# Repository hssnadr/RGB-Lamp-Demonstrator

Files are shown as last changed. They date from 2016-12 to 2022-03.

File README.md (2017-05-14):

# RGB Lamp

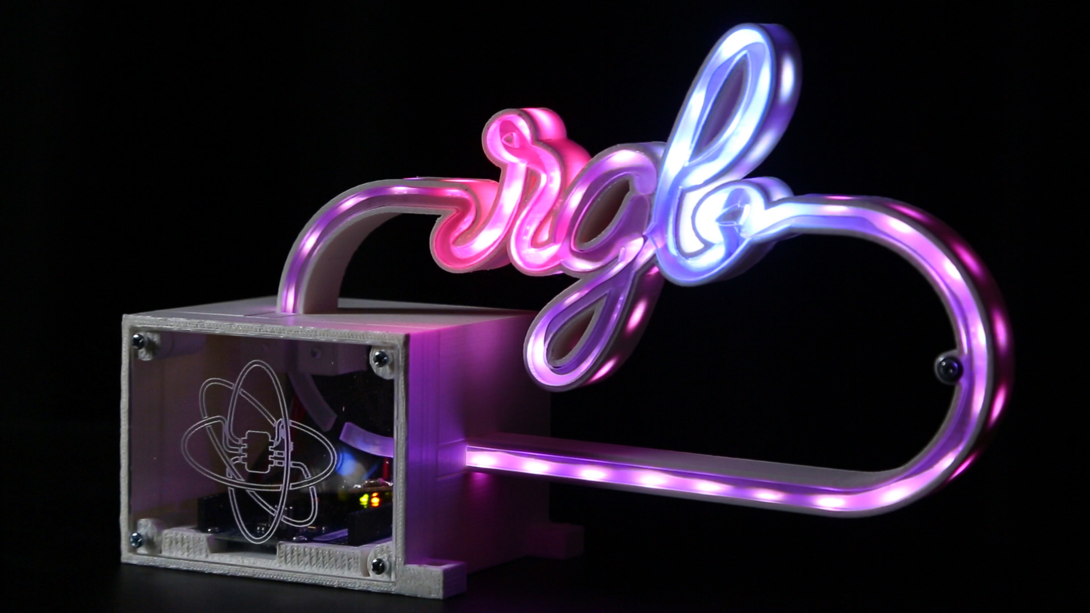
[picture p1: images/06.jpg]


## Presentation

This lamp project is a demonstrator dedicated to highlight Mobile-Lab technological resources. It allows to interact with its colors by moving the hand. How does it work ?
 1. the user records 3 gestures, each one corresponding to a color component of the light (red, green or blue);
 2. then he moves his hand reproducing those gestures, this way he can regulate the proportion of RGB colors in the light and create any kind of colors;
 3. the user can record any kind of gesture, let's try different patterns!

Full presentation video on Vimeo: https://vimeo.com/197767041

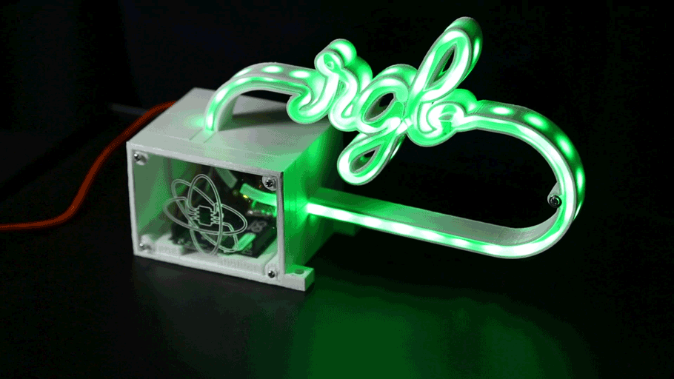
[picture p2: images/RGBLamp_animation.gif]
  
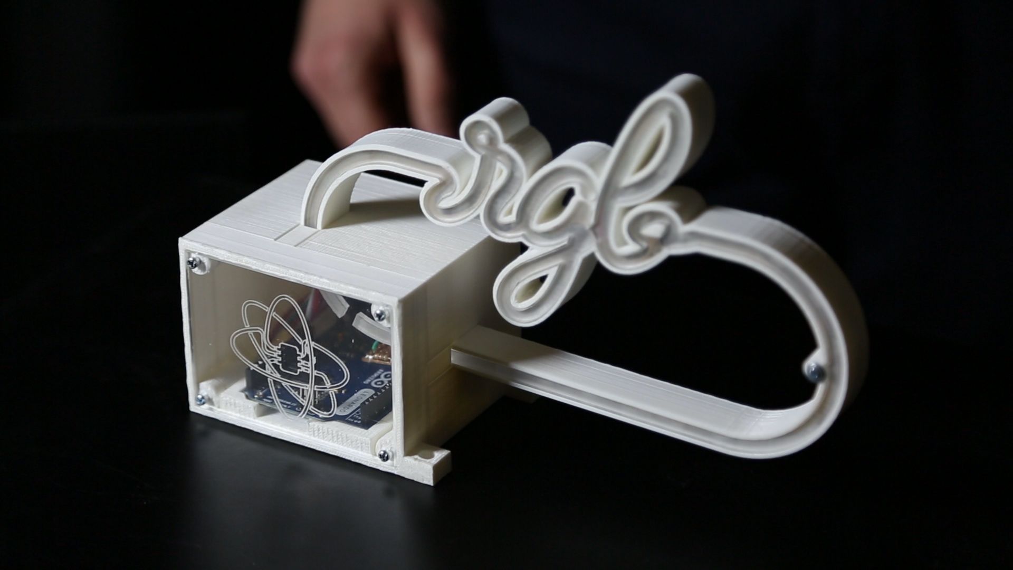
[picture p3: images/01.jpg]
  
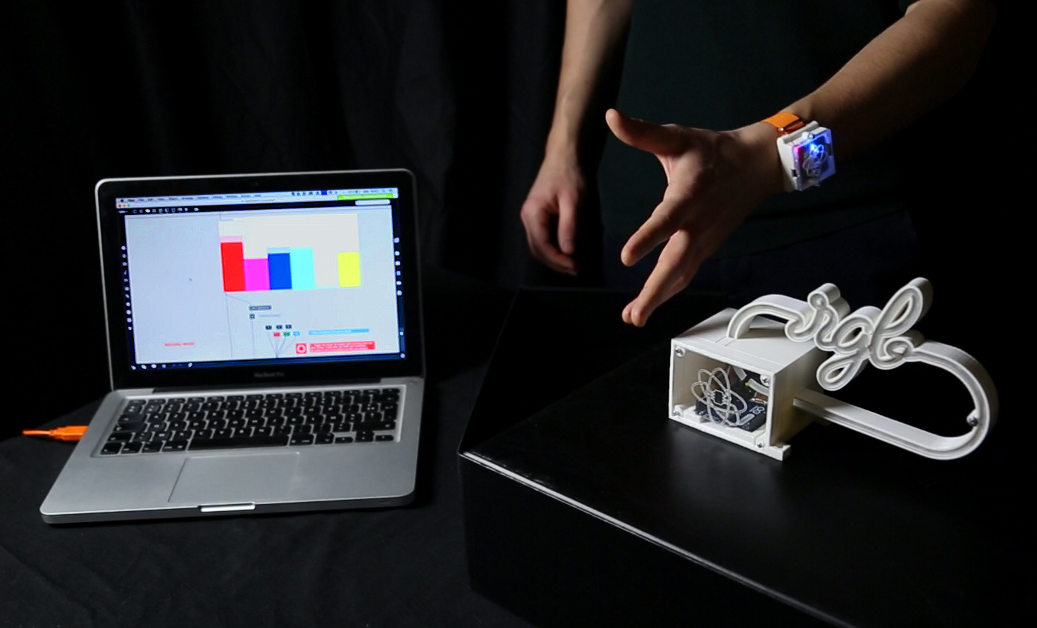
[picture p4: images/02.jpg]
  
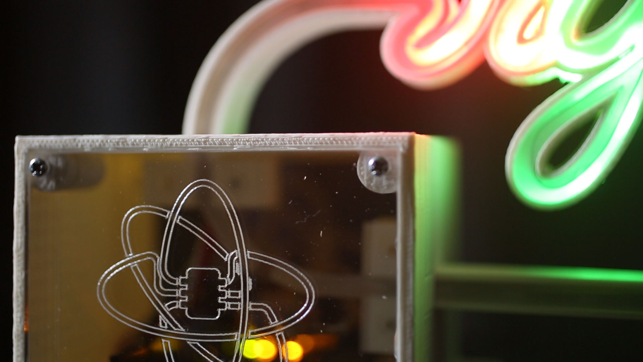
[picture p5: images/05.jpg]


The purpose of this project is to highlight usages around those technologies and enhance collaboration with potential development partners.

This demonstrator was developed using **Movuino** gesture sensor and **IRCAM** algorithm libraries for real time gesture recognition. This library is include into their MuBu package for Max/MSP. It gives Max objects to easily store and manage data flows and includes their XMM libraries.
* Presentation: https://www.julesfrancoise.com/mubu-probabilistic-models/
* Download link: http://forumnet.ircam.fr/fr/produit/mubu/

## Content
Here you will find:
* **1_Movuino_FirmwareOSC/Arduino** this folder contains the firmware for the Movuino. You can edit and use it with the Arduino software;
* **2_CybRGB_ArduinoFirmware** this folder contains the firmware of the lamp. You can also edit it using the Arduino software;
* **CybRGB.maxpat** this file is used as interface to control the lamp.

## Installation
  
### Movuino (1_Movuino_FirmwareOSC/)
* Download and install the Arduino software: https://www.arduino.cc/en/Main/Software
* Download and install the CP2014 driver: http://www.silabs.com/products/mcu/Pages/USBtoUARTBridgeVCPDrivers.aspx
* Inside Arduino
  * Install the card ESP8266 following those instructions: https://learn.sparkfun.com/tutorials/esp8266-thing-hookup-guide/installing-the-esp8266-arduino-addon
 * Go to Tools/Board, select "Adafruit HUZZAH ESP8266" with:
      * CPU Frequency: 80 MHz
      * Flash Size: 4M (3M SPIFFS)
      * Upload Speed: 115200
      * Port: the one corresponding to the Movuino
  * Copy the content of the Arduino folder into your own Arduino folder (Macintosh and Windows: Documents/Arduino). It includes the libraries you need, but you can also install them by yourself. In the Arduino software go to "Sketch/Include Library/Manage Libraries...", here seek and install:  
    * I2Cdev
    * OSC
    * MPU6050
      * for this one you need to make a correction in the library file. Go to Arduino/libraries/MPU6050/ and edit the file "MPU6050.h" (open it in NotePad, SublimeText, NotePad++ or anykind of text editor).
        * line 58, replace the line: `#define MPU6050_DEFAULT_ADDRESS MPU6050_ADDRESS_AD0_LOW`
        * **by:** `#define MPU6050_DEFAULT_ADDRESS MPU6050_ADDRESS_AD0_HIGH`
  * Restart Arduino and follow instructions inside the code (ip, rooter, password, port...)
     * `const char * ssid = "my_box_name";` set the name of your wifi network
     * `const char * pass = "my_password";` type the password of the network
     * `const char * hostIP = "192.168.1.35";` set the ip address of **YOUR COMPUTER** which is also connected to the same Wifi network and on which you will use the Max file
     * `const unsigned int port = 7400;` (optional) here you can set the port on which the data are sent. If you don't use other ports or if you have no idea of what I'm talking about you can let 7400.
     * `const unsigned int localPort = 3011;` (optional) here you can set the port on which Movuino can receive OSC message. Idem, better to let it at 3011.
  * Upload firmware and check on the Arduino monitor window if everything is good!
  * You can shut down (partially) and turn on the Movuino by pressing the button during 1 second.
  * **You can also send message to the Movuino, also using OSC.**
  
### RGB Lamp firmware (2_CybRGB_ArduinoFirmware/)
The lamp has been developped with an Arduino Leonardo and NeoPixel Led Strip from Adafruit. Here you will find some information concerning the Led Strip:
* How to use it: https://learn.adafruit.com/adafruit-neopixel-uberguide/basic-connections
* Concerning the batteries: https://learn.adafruit.com/adafruit-neopixel-uberguide/basic-connections

To use it you only need to plug the USB port to your computer, to plug the power supply and to directly go next step with the Max/MSP patch.
  
To modify the firmware, download the content of the folder and paste it into your Arduino folder (Macintosh and Windows: Documents/Arduino). The folder include the NeoPixel library but I recommend you to download it yourself: in the Arduino software go to "Sketch/Include Library/Manage Libraries...", here seek and install "Adafruit NeoPixel".
  
Now you can play with the code and update the firmware. Be sure to choose "Arduino Leonardo" (Tools/Board/) before to upload the code.
  
### CybRGB.maxpat
To run the Max file, you'll need to install the MuBu package. It's very simple!
* download the package on the MuBu page: http://forumnet.ircam.fr/fr/produit/mubu/
* unzip the folder "MuBuForMax" and simply past it into the proper folder:
 * **On Macintosh**
    * go to Applications folder, right click on the **Max** icon and choose "Show Package Contents"
    * paste the MuBuForMax folder into Contents/Resources/C74/packages
    * launch or restart Max and that's it.
  * **On Windows**
    * paste the MuBuForMax folder into /Documents/Max 7/Packages
    * launch or restart Max and that's it.
    
Before to use the script you will also need to make the lamp recognized by the Max patch. Once again it's very simple, you simply need plug the lamp to your computer, then print the available USB port of your computer, check which one correspond  to the lamp and finally set this port into the Max patch. Here the principle (not the same patch but exactly the same workflow):



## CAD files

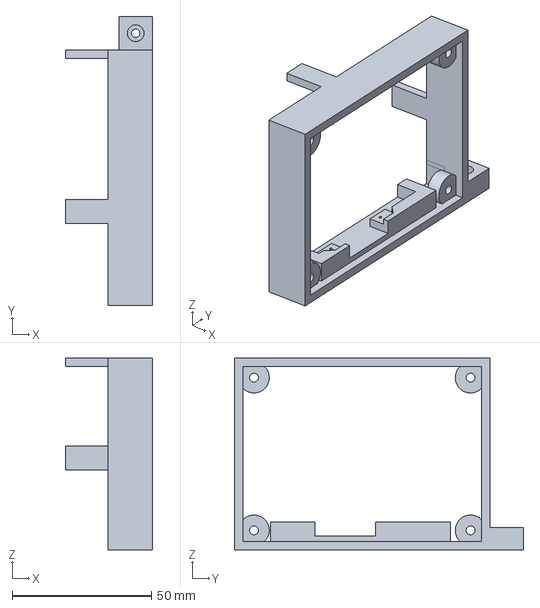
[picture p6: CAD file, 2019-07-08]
01_MakingRessources/3DModels/STP/Base_Front.stp
31.1 x 103.8 x 68.9 mm

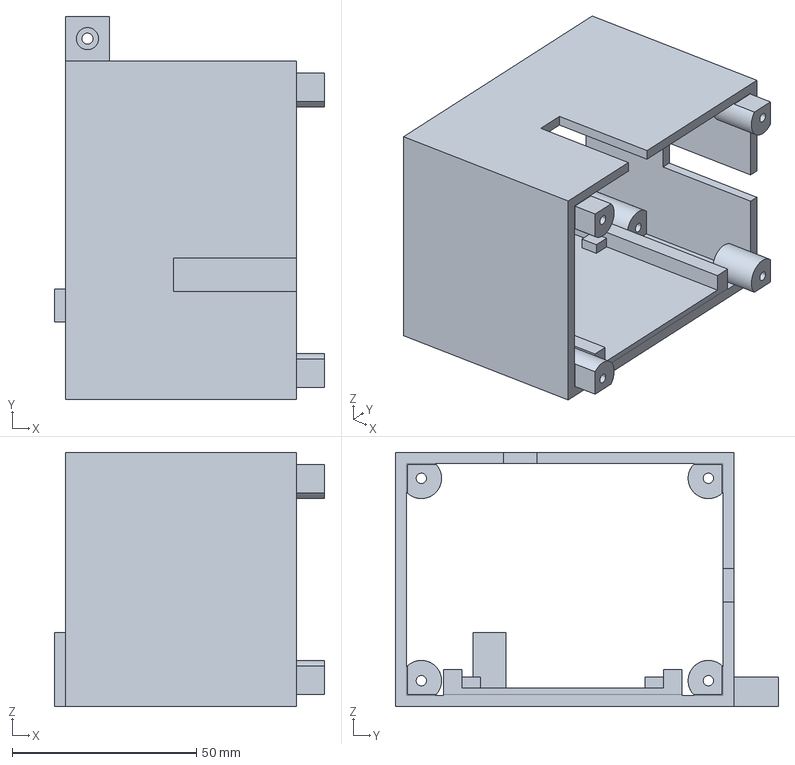
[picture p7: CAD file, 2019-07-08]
01_MakingRessources/3DModels/STP/Base_Back.stp
73.3 x 103.8 x 68.9 mm

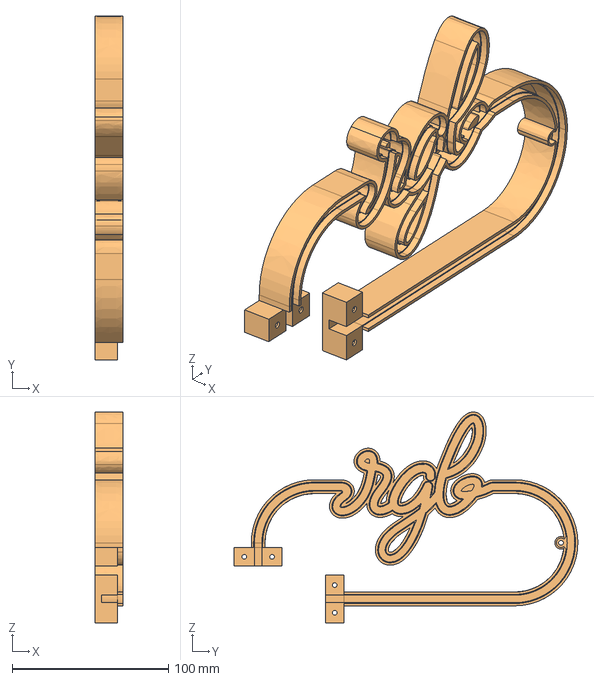
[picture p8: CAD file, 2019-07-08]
01_MakingRessources/3DModels/STP/RGB_Case.stp
17.7 x 220.0 x 135.0 mm

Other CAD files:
01_MakingRessources/3DModels/CATIA/Base_Back.CATPart
01_MakingRessources/3DModels/CATIA/Base_Front.CATPart
01_MakingRessources/3DModels/CATIA/RGBLamp_Product.CATProduct
01_MakingRessources/3DModels/CATIA/RGB_Case.CATPart
01_MakingRessources/3DModels/STL/Base_Back.stl
01_MakingRessources/3DModels/STL/Base_Front.stl
01_MakingRessources/3DModels/STL/RGB_Case.stl

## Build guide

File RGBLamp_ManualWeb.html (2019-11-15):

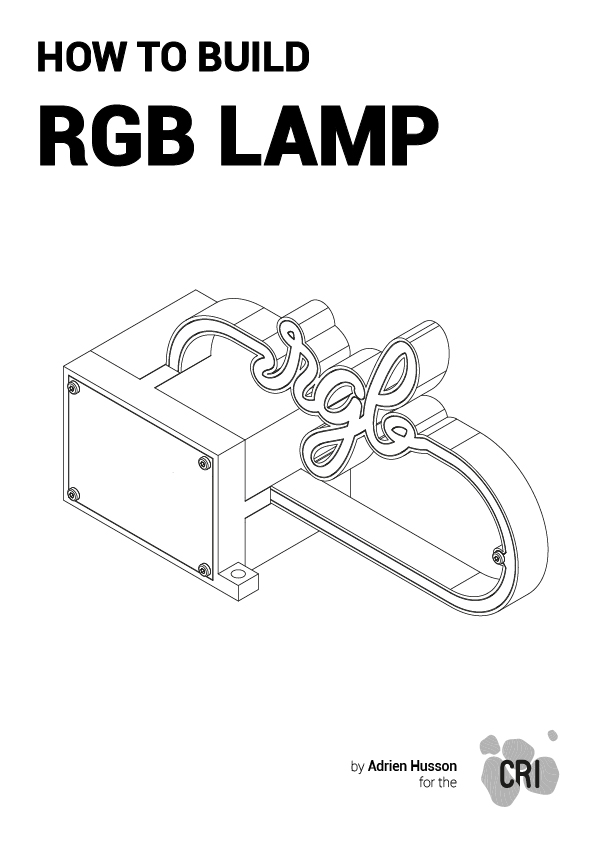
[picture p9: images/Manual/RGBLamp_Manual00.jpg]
RGBLamp_Manual00


Download manual (https://github.com/hssnadr/RGB-Lamp-Demonstrator/raw/master/RGBLamp_ManualBooklet.pdf)

### Furnitures

RGBLampGif

Get all the files you'll need and start following the tutorial

Download ressources (https://github.com/hssnadr/RGB-Lamp-Demonstrator/archive/master.zip) See on Github (https://github.com/hssnadr/RGB-Lamp-Demonstrator)

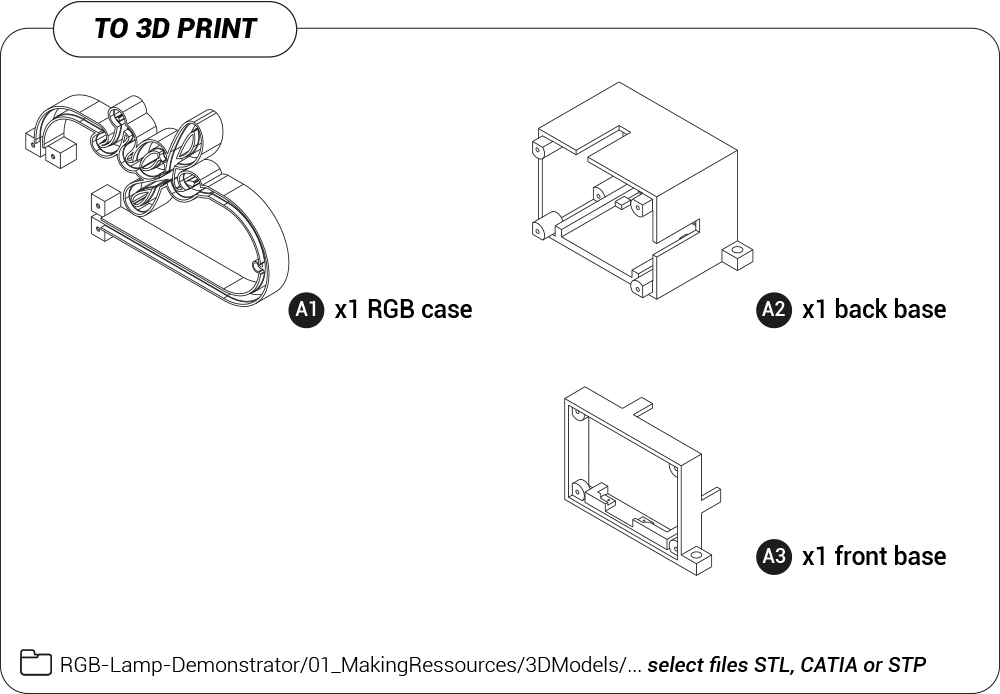
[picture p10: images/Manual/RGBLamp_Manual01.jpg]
RGBLamp_Manual01
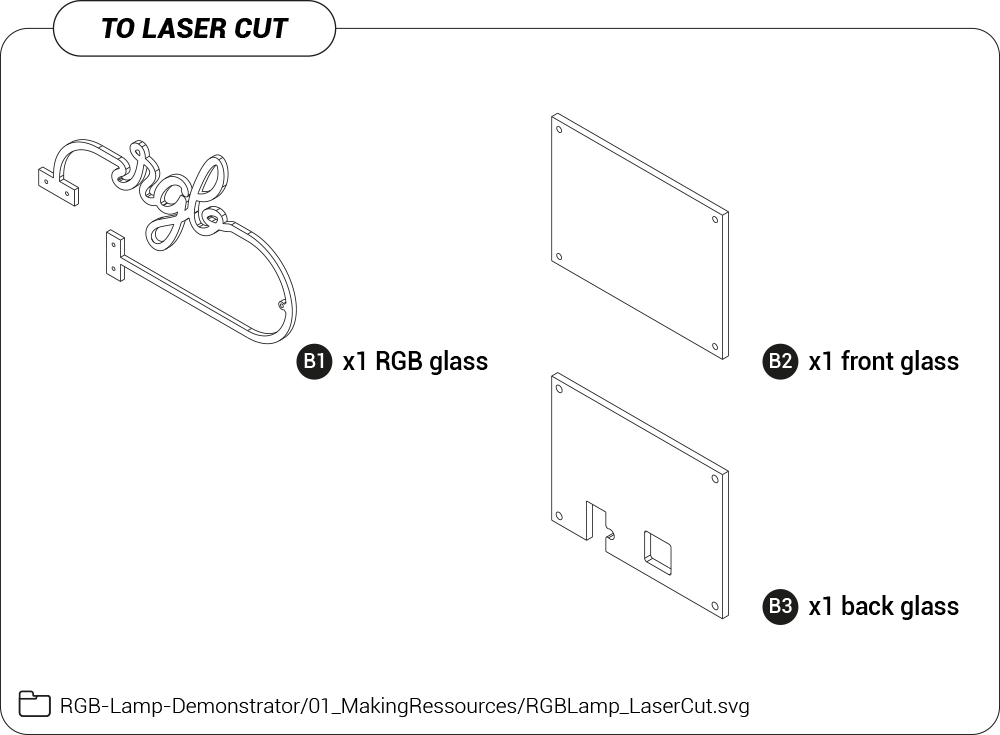
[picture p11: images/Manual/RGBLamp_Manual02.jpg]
RGBLamp_Manual02
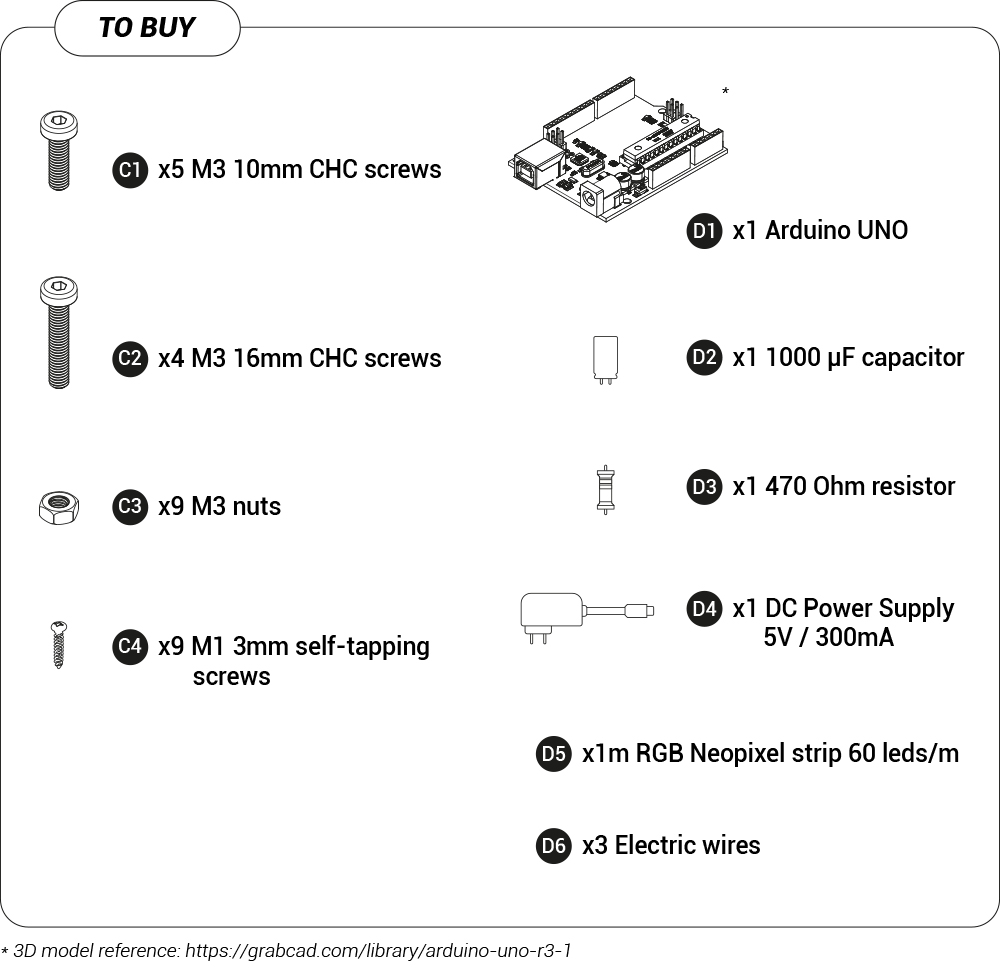
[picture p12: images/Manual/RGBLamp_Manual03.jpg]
RGBLamp_Manual03
  

### Electronic

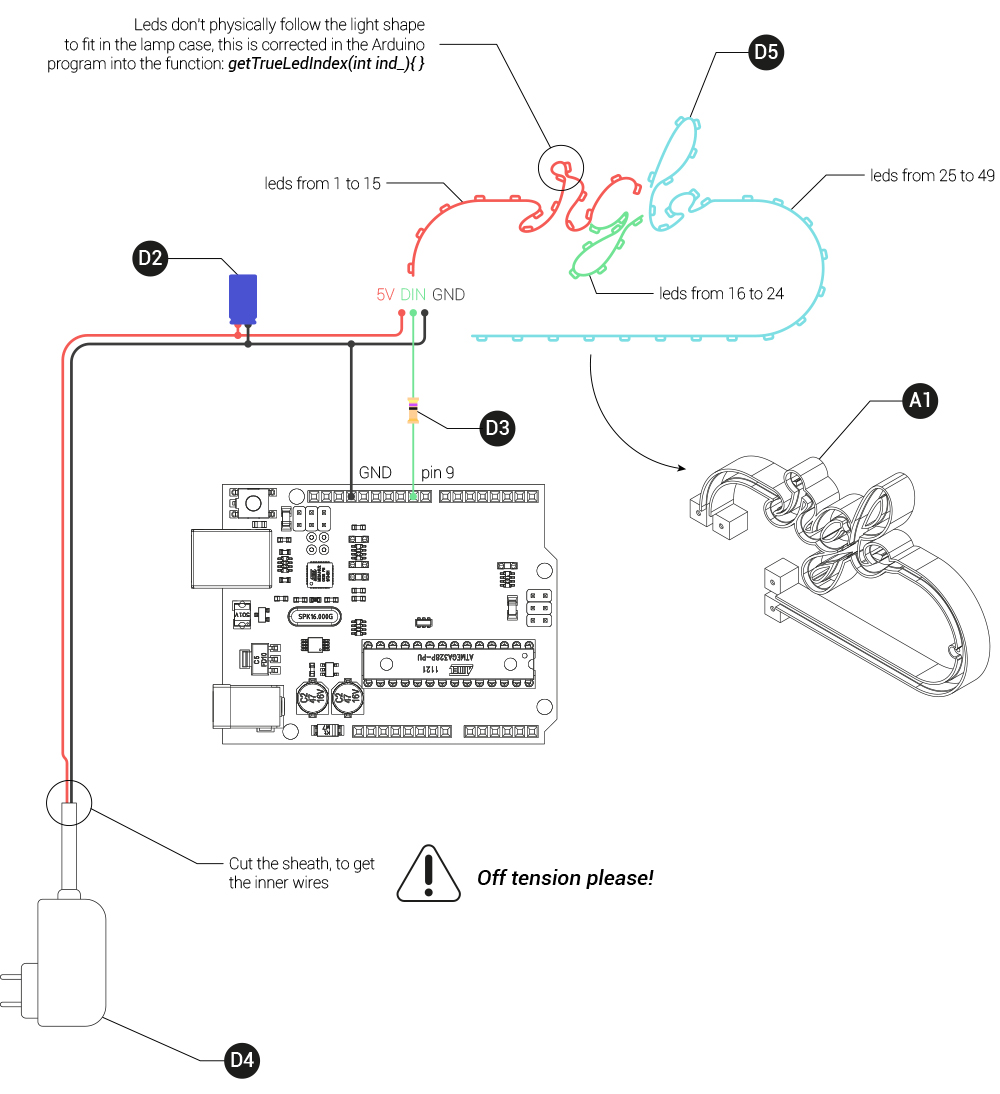
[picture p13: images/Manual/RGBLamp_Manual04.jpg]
RGBLamp_Manual04
RGBcloseUp 

### Assembly

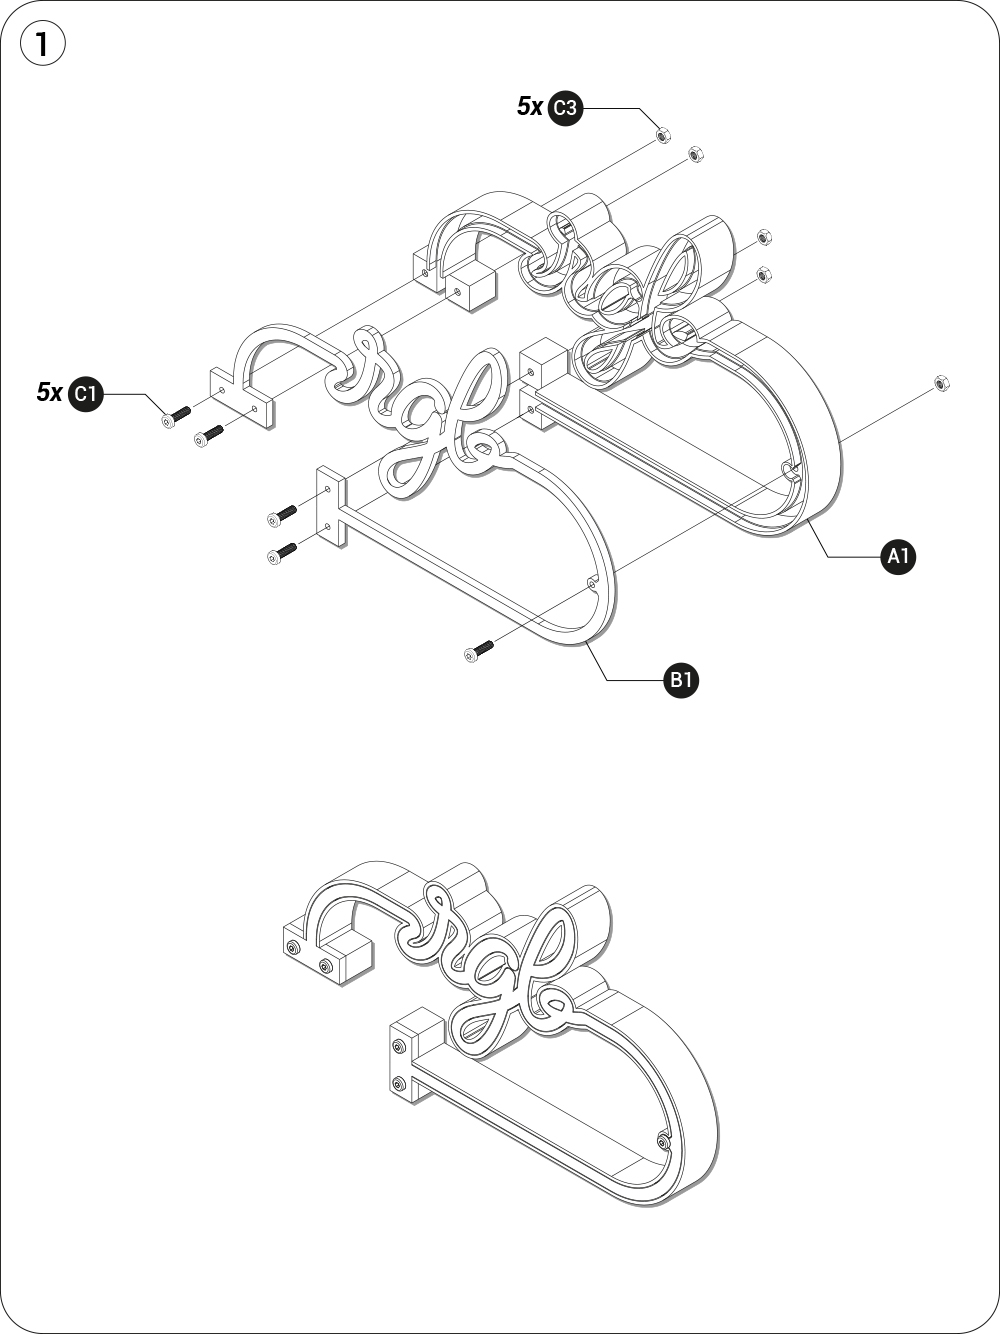
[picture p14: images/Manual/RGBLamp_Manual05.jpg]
RGBLamp_Manual05
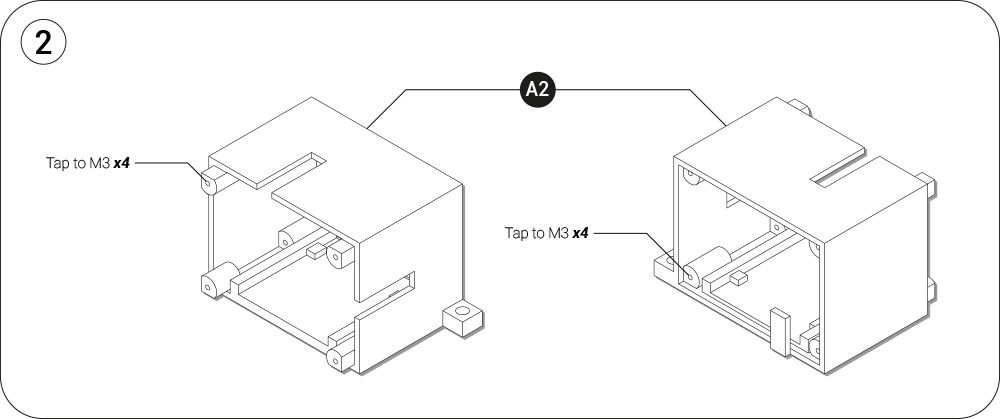
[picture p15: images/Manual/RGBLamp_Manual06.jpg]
RGBLamp_Manual06
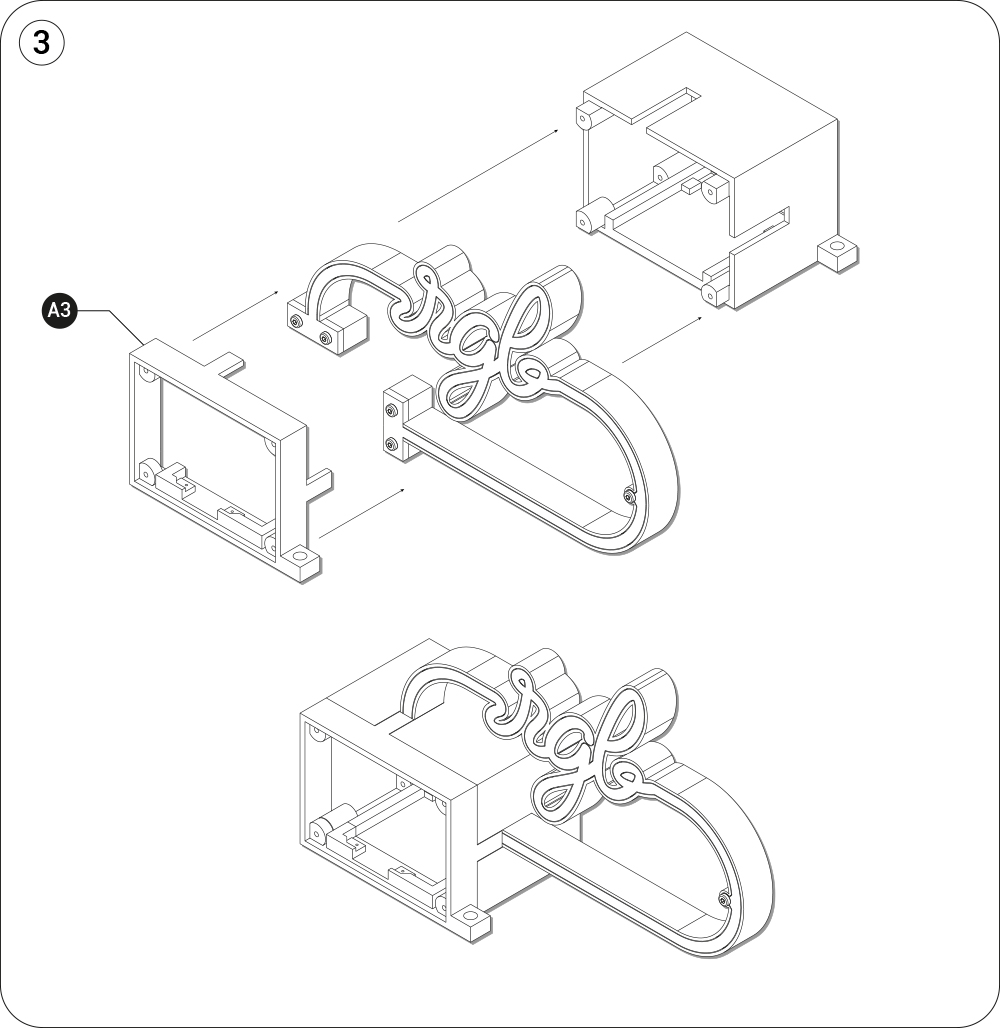
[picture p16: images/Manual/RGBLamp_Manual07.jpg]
RGBLamp_Manual07
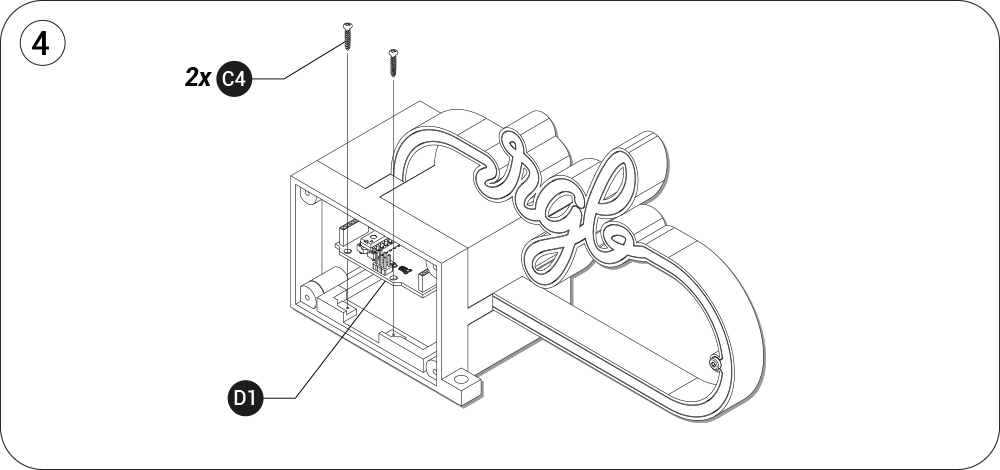
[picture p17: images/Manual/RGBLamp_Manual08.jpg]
RGBLamp_Manual08
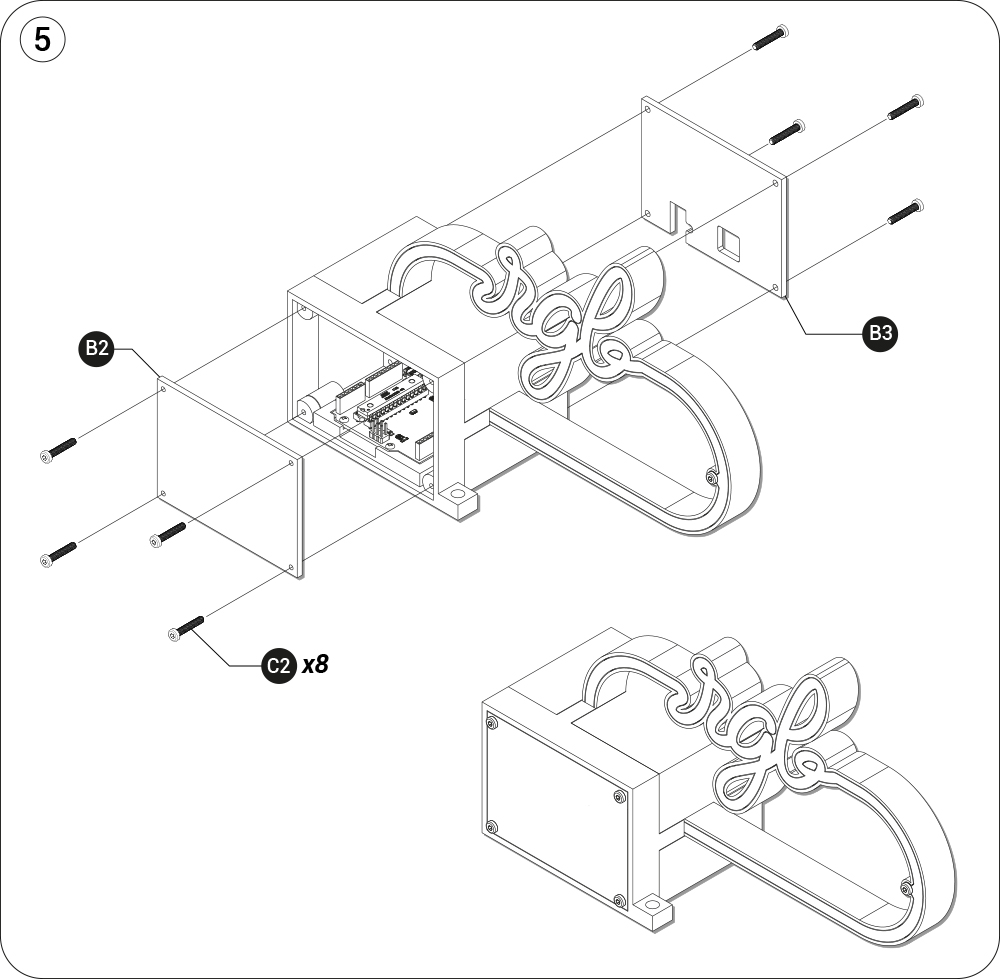
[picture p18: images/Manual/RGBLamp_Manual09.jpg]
RGBLamp_Manual09
RGB3Dprint     

### Set-Up

RGB02

PictoArduino

Download and install Arduino (https://www.arduino.cc/en/main/software)

1. Run the RGBLamp.ino firmware with Arduino
2. You’ll need to install the Adafruit Neopixel library:
  Sketch/Include a library/Manage libraries
3. Search for «Adafruit Neopixel» in the search tab and the install latest version
4. Upload the program on your board

PictoFolder

RGB-Lamp-Demonstrator/02_ArduinoFirmware/RGBLamp/ (https://github.com/hssnadr/RGB-Lamp-Demonstrator/tree/master/02_ArduinoFirmware/RGBLamp)

PictoProcessing

Download and install Processing (https://processing.org/download/)

  1. Run the RGBLamp.pde file with Processing while the lamp is plugged on a USB port of your computer
  2. You’ll need to install the oscP5 library:
    Sketch/Import library.../Add a library...
  3. Search for «oscP5» in the search tab and the install latest version
  4. Go to line 40 into the Processing code and set the USB port where your Arduino is plugged

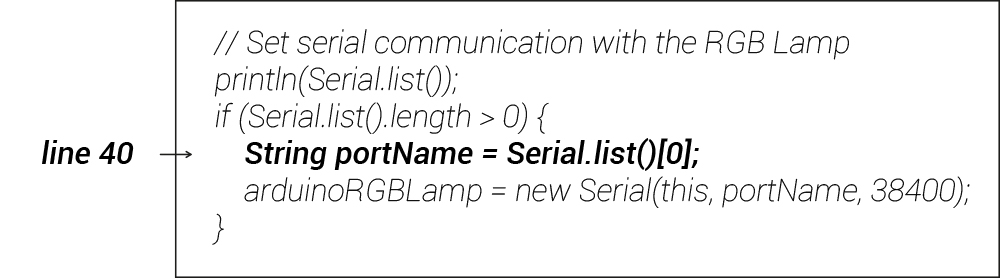
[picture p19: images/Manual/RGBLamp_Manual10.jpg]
RGBLamp_Manual10


PictoFolder

RGB-Lamp-Demonstrator/03_ProcessingApplication/RGBLamp/ (https://github.com/hssnadr/RGB-Lamp-Demonstrator/tree/master/03_ProcessingApplication/RGBLamp)

PictoProcessing

Download and install Movuina (http://www.movuino.com#dlmovuina)

Launch Movuina and set-up by following the Quick Start tutorial

Quick start tutorial (http://www.movuino.com/index.php/quick-start/)

Once its done, you can play with the XMM algorithm (http://ismm.ircam.fr/software/xmm-probabilistic-models-for-motion-recognition-and-mapping/) developped by IRCAM

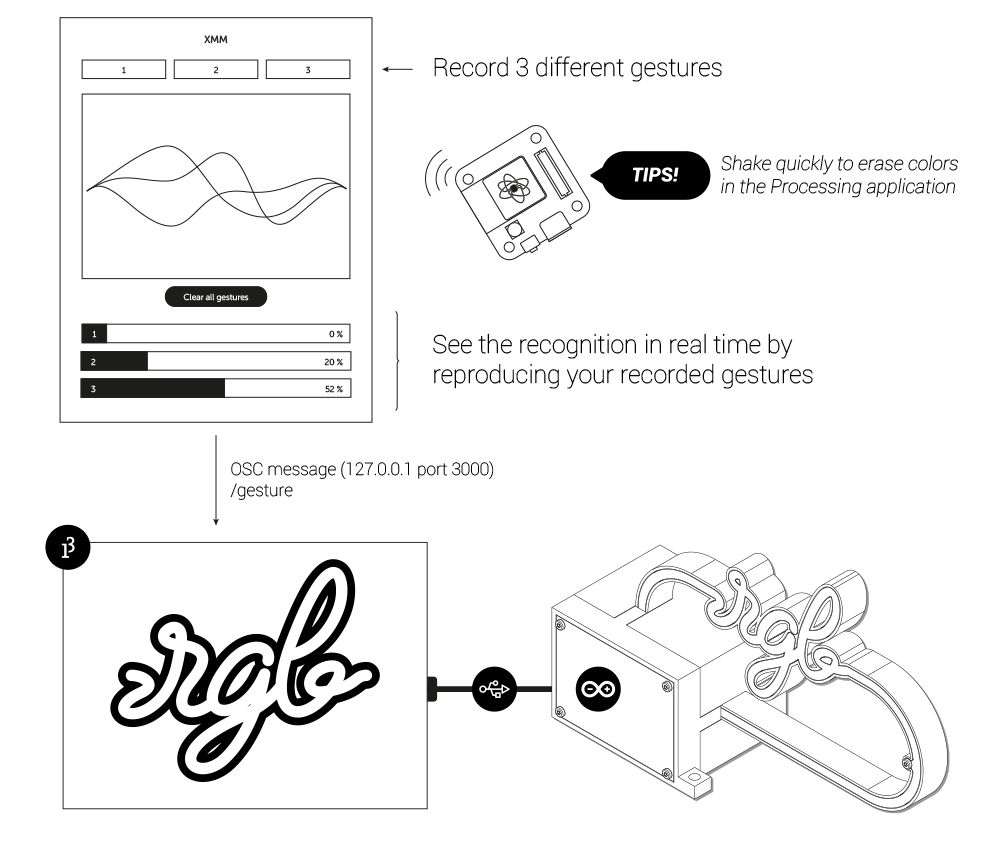
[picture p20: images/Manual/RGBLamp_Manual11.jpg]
RGBLamp_Manual11


The data are automatically sent to Processing and you can enjoy the reaction!

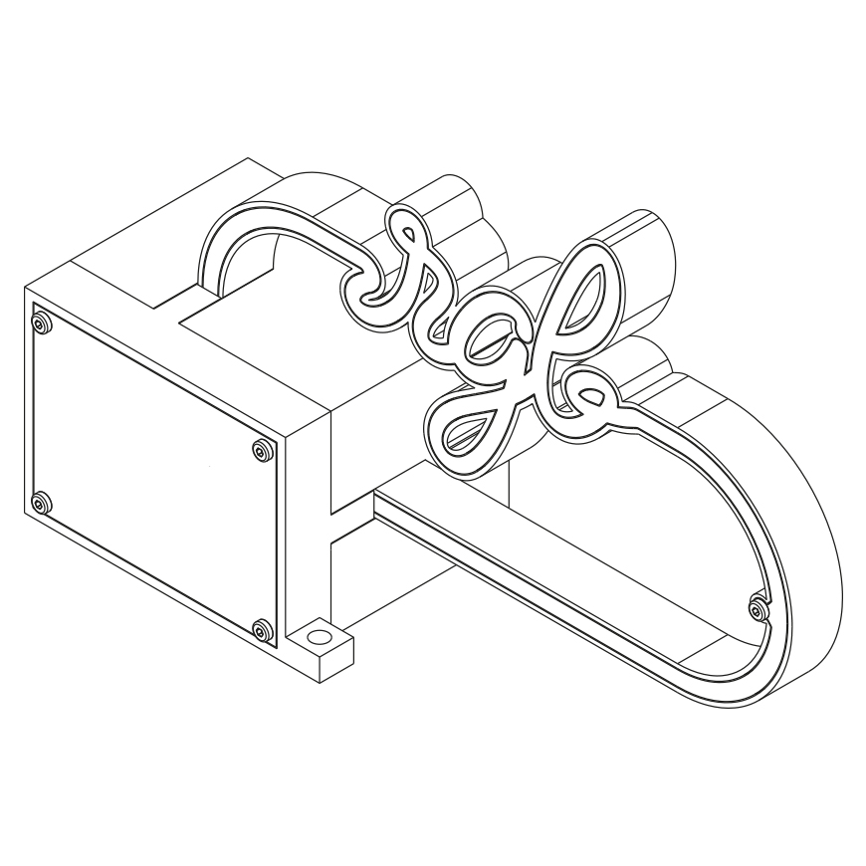
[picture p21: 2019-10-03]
images/Manual/RGBLamp_Square.jpg

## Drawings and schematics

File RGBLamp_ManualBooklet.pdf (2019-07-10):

# RGB LAMP

# HOW TO BUILD

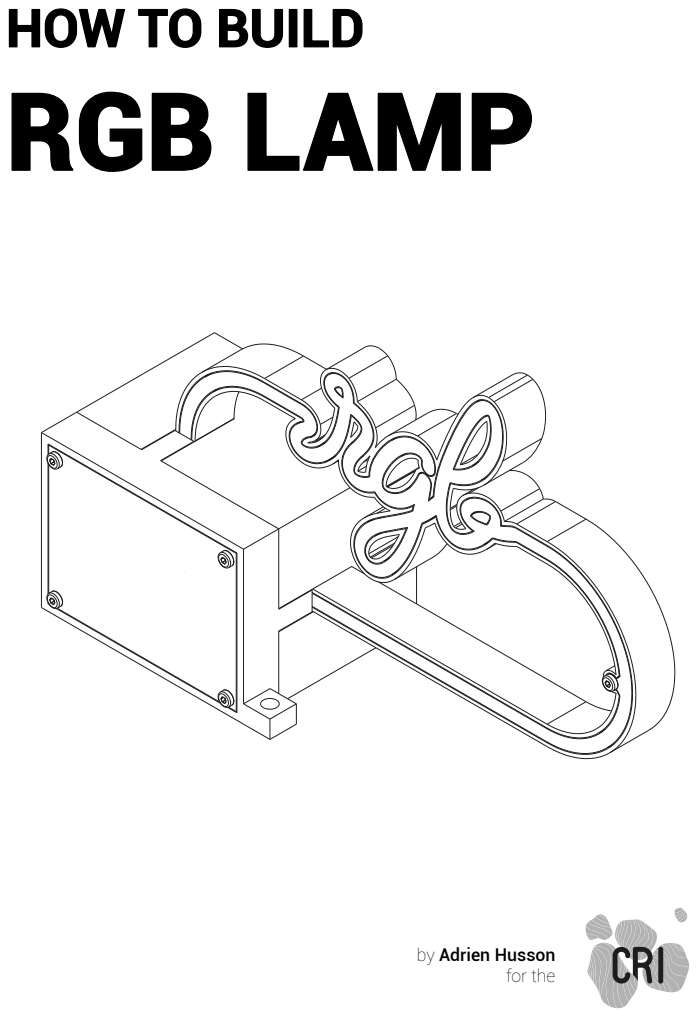
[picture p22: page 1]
for the

by Adrien Husson

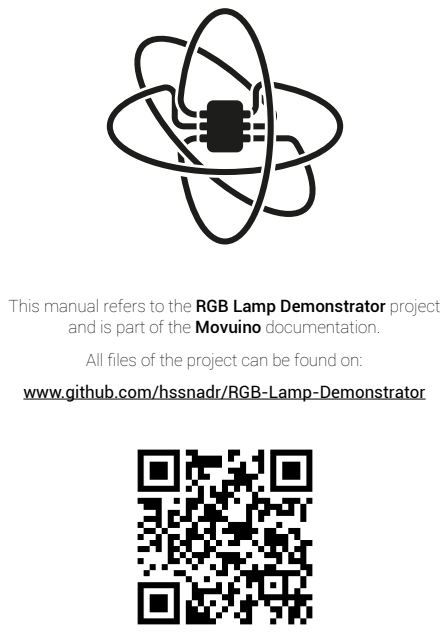
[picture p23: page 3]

This manual refers to the RGB Lamp Demonstrator project
and is part of the Movuino documentation.
All files of the project can be found on:
www.github.com/hssnadr/RGB-Lamp-Demonstrator

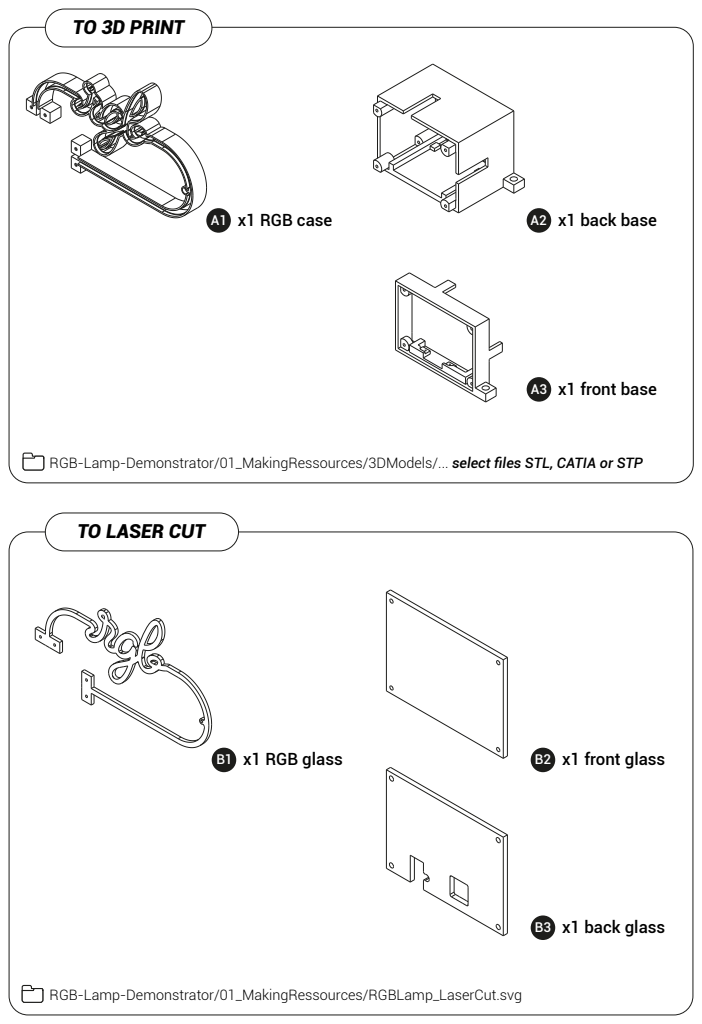
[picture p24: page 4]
TO 3D PRINT; x1 back base; x1 front base; A1 x1 RGB case; B1 x1 RGB glass; B2 x1 front glass; B3 x1 back glass

RGB-Lamp-Demonstrator/01_MakingRessources/3DModels/... select files STL, CATIA or STP

TO LASER CUT

RGB-Lamp-Demonstrator/01_MakingRessources/RGBLamp_LaserCut.svg

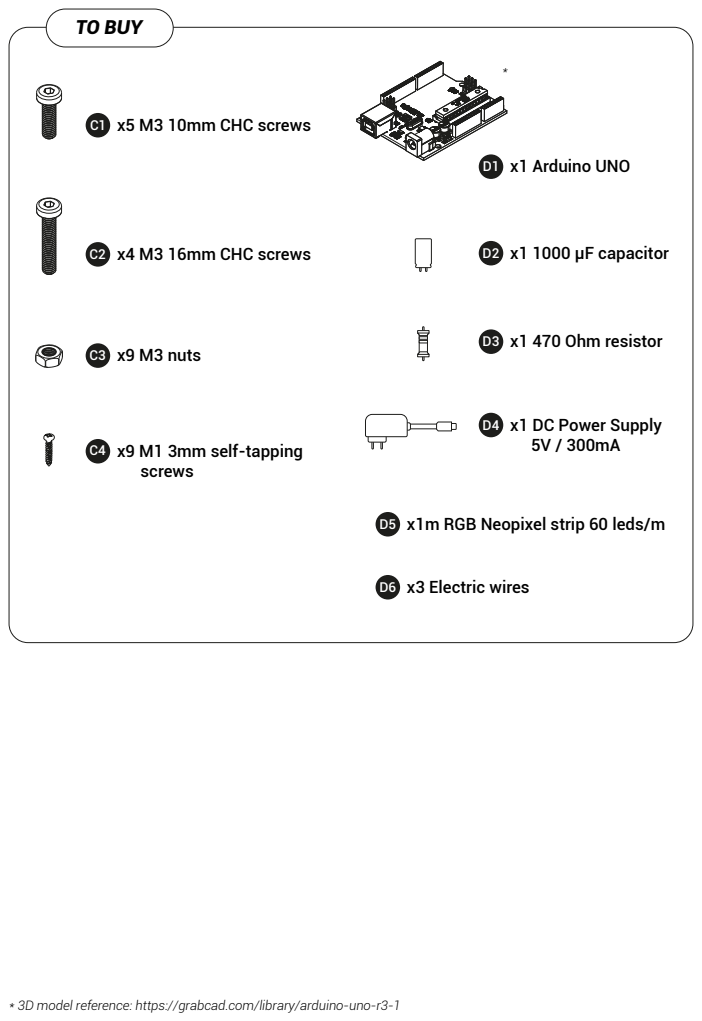
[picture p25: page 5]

D5 x1m RGB Neopixel strip 60 leds/m

* 3D model reference: https://grabcad.com/library/arduino-uno-r3-1

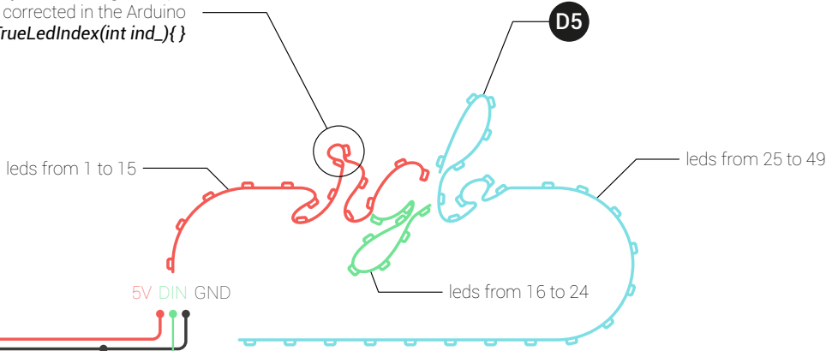
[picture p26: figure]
leds from 25 to 49 leds from 1 to 15; 5V DIN GND; leds from 16 to 24
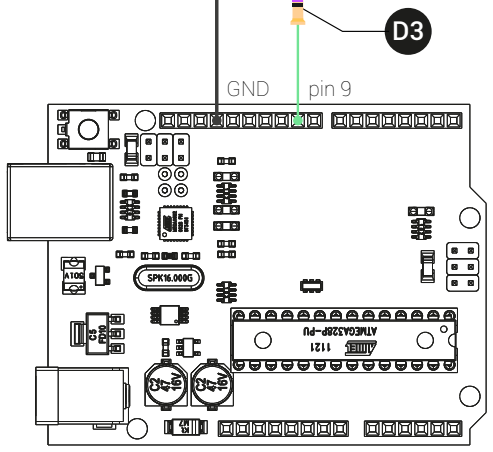
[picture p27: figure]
GND; pin 9

Cut the sheath, to get
the inner wires

Leds don’t physically follow the light shape to fit in the lamp case, this is corrected in the Arduino program into the function: getTrueLedIndex(int ind_){ }

# ELECTRONIC

To make the electronic part, you need to cut your 1 meter Neopixel leds strip into 3 parts, then sold it in a way it fits into the RGB case and following this diagram.

Off tension please!

D2

D4

A1

# ASSEMBLY

1

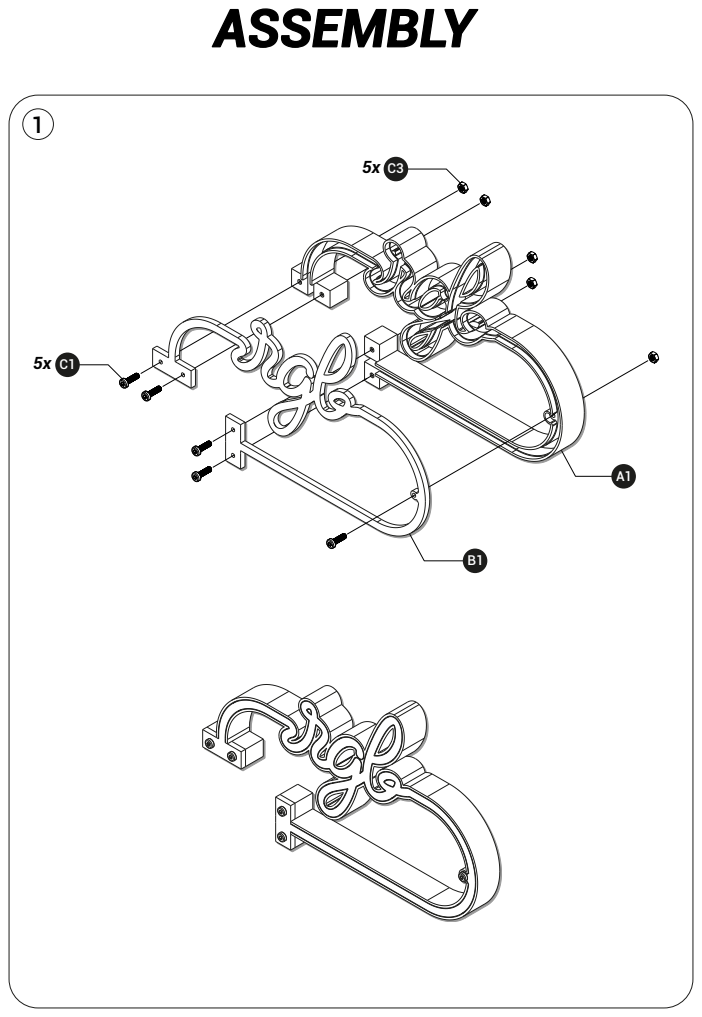
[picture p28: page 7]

2

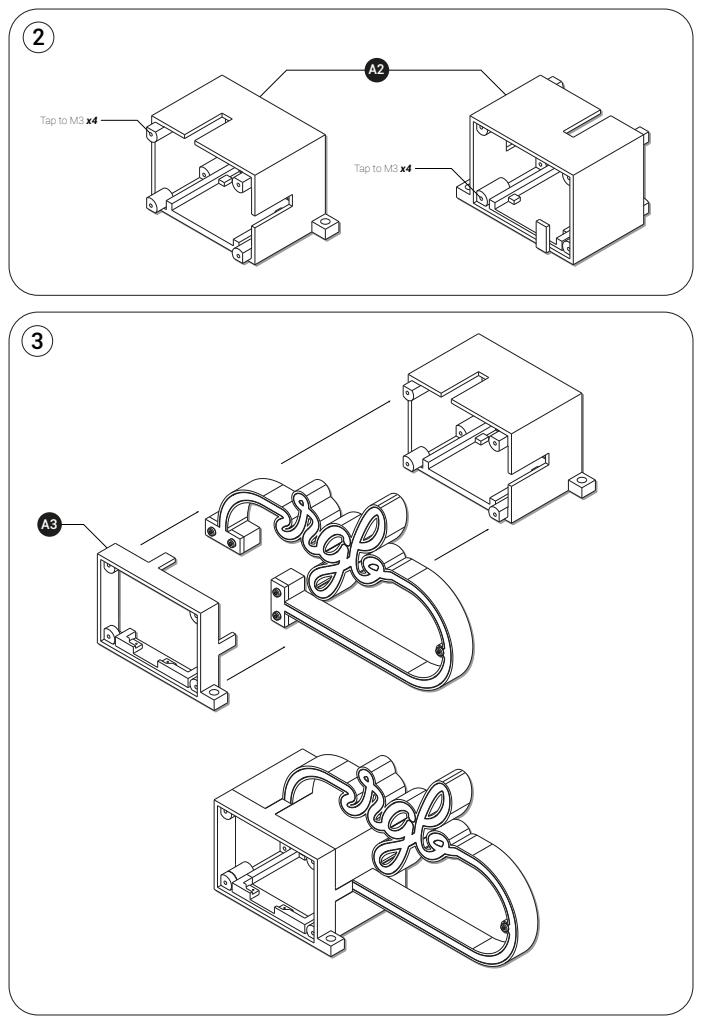
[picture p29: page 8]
Tap to M3 x4

4

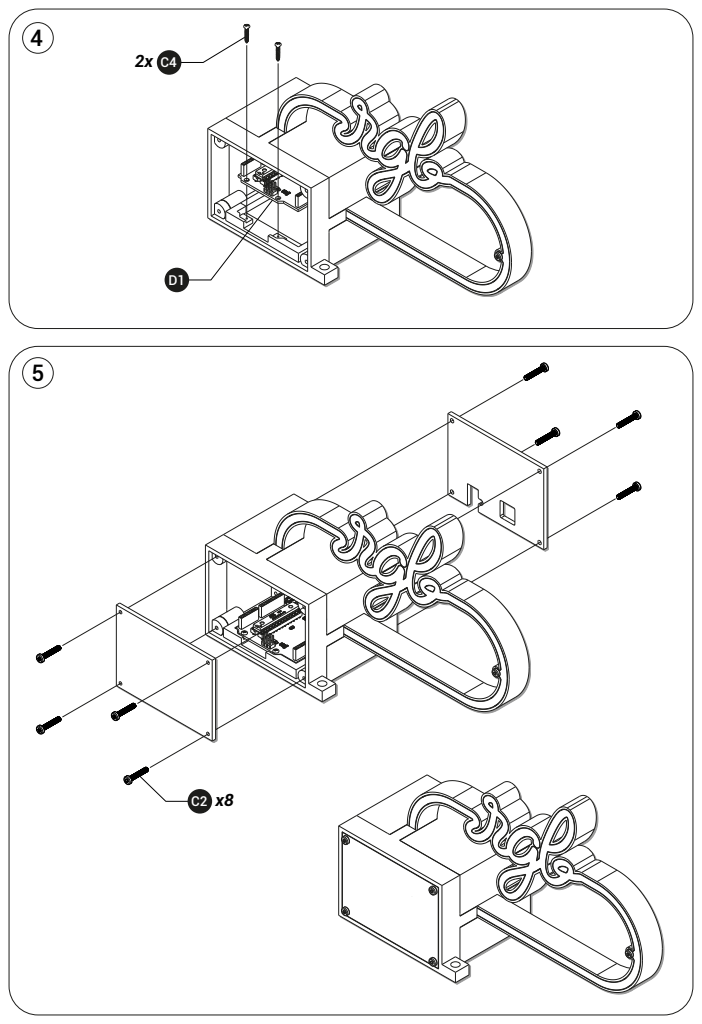
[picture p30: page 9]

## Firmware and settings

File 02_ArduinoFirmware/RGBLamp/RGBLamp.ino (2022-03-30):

/*
 * This project is part of the Movuino demo tutorial from: http://www.movuino.com/
 * Page of the project: http://www.movuino.com/index.php/portfolio/rgb-lamp/
 * Github: https://github.com/hssnadr/RGB-Lamp-Demonstrator
 */

// LED strip
#include <Adafruit_NeoPixel.h>
#ifdef __AVR__
#include <avr/power.h>
#endif
#define pinLed 9                                                                 // Pin controling the led strip behavior
#define nPix 49                                                                  // number of pixels used in the strip
Adafruit_NeoPixel strip = Adafruit_NeoPixel(nPix, pinLed, NEO_GRB + NEO_KHZ800); //   NEO_KHZ800  800 KHz bitstream (most NeoPixel products w/WS2812 LEDs)

// Auto loop: play random animation before first serial input
bool _isAutoLoop = true;

// RGB values
int stripOrder[] = {0, 1, 2, 3, 4, 5, 6, 7, 9, 8, 10, 11, 12, 14, 13, 15, 16, 17, 21, 20, 19, 18, 22, 28, 27, 26, 25, 24, 23, 29, 30, 32, 31, 33, 34, 35, 36, 37, 38, 39, 40, 41, 42, 43, 44, 45, 46, 47, 48};
boolean isNewColor = false;
byte stripRed[nPix];
byte stripGreen[nPix];
byte stripBlue[nPix];
boolean isColorSet;
int r = 0;
#define r0 4  // led index where letter 'R' starts
#define r1 13 // led index where letter 'R' ends
int g = 0;
#define g0 13 // led index where letter 'G' starts
#define g1 23 // led index where letter 'G' ends
int b = 0;
#define b0 23 // led index where letter 'B' starts
#define b1 34 // led index where letter 'B' ends

long timer0;
long timer1;

// Serial variables
int inByte = 0;    // incoming serial byte
char buffer[40];   // buffer to store incoming bytes
int index = 0;     // current index of the buffer
char msgAdr = 'X'; // address of received messages
int msgVal = -1;   // values of received messages

void setup()
{
  // Serial Port begin
  Serial.begin(9600);

  // LED strip setup
  // strip.setBrightness(50);
  strip.begin(); // This initializes the NeoPixel library.
  strip.show();  // Initialize all pixels to 'off'
  timer0 = millis();
}

void loop()
{
  if (_isAutoLoop)
  {
    autoLoop();
  }
  // Serial.println("HERE");
  HHMM_follower();
  // WheelAnimation();
}

int getTrueLedIndex(int ind_)
{
  // REAL STRIP ORDER
  // to be integrated properly into the lamp, the led strip has been cut and re-solder.
  // I had to modify the order of the led to get the expected effect. This function permits to
  //{1,2,3,4,5,6,7,8,10,9,11,12,13,15,14,16,17,18,22,21,20,19,23,29,28,27,26,25,24,30,31,33,32,34,35,36,37,38,39,40,41,42,43,44,45,46,47,48,49}
  //       |                        |                             |                             |
  //      red                     green                          blue                          end
  //"RED" = 5 -> 13
  //"GREEN" = 15 -> 23
  //"BLUE" = 29 -> 34

  return stripOrder[ind_];
}

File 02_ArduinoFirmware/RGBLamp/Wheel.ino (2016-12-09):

int indWheel = 0;
int oldIndWheel1 = 0;
int oldIndWheel2 = 0;
boolean isLoading = false;

void WheelAnimation() {
  if (!isLoading) {
    shutDownStrip();
  }

  setPixWheel(indWheel, 1);
  setPixWheel(oldIndWheel1, 4);
  setPixWheel(oldIndWheel2, 8);

  delay(57);
  strip.show();

  oldIndWheel1 = indWheel;
  oldIndWheel2 = oldIndWheel1;

  if (indWheel < nPix - 1) {
    if (indWheel == 2) {

    }
    indWheel++;
  }
  else {
    indWheel = 0;
    isLoading = !isLoading ;
    shutDownStrip();
  }
}


void shutDownStrip() {
  for (int i = 0; i < nPix; i++) {
    strip.setPixelColor(getTrueLedIndex(i), strip.Color(0, 0, 0));
  }
}

void setPixWheel(int i_, int r_) {
  if (i_ < r0) {
    strip.setPixelColor(getTrueLedIndex(i_), strip.Color(255 / r_, 255 / r_, 255 / r_));
  }
  if (i_ >= r0) {
    strip.setPixelColor(getTrueLedIndex(i_), strip.Color(255 / r_, 0, 0));
  }
  if (i_ >= g0) {
    strip.setPixelColor(getTrueLedIndex(i_), strip.Color(0, 255 / r_, 0));
  }
  if (i_ >= b0) {
    strip.setPixelColor(getTrueLedIndex(i_), strip.Color(0, 0, 255 / r_));
  }
  if (i_ > b1) {
    strip.setPixelColor(getTrueLedIndex(i_), strip.Color(255 / r_, 255 / r_, 255 / r_));
  }
}

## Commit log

2016-12-09 i2c library
2019-07-08 3Files and laser cut
    [Base_Back.CATPart, Base_Back.stl, Base_Back.stp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]
